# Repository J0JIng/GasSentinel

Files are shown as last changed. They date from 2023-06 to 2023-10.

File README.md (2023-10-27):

# GasSentinel

## Overview 
Gas leaks can be dangerous but hard to detect. This project aims to use edge AI to provide low-latency, accurate detection of gas leaks. In particular, these are propane, butane and natural gas.<br>
It is also possible to detect indicative gases such as H<sub>2</sub>S.

## Algorithm and Detection Principles
Interpreting gas sensor resistances is complex and may require specialized knowledge in electrochemical sensor behaviors. Resistance of the sensing element is nontrivially influenced by ambient conditions, and even past gas exposure events. As such, this situation provides an opportunity to utilize ML techniques to interpret the data.<br>

This project utilizes the BSEC software (which runs on the microcontroller) to run the associated signal processing/fusion and ML model. Refer to Figure 1 below for the confusion matrix and F1 scores:<br>

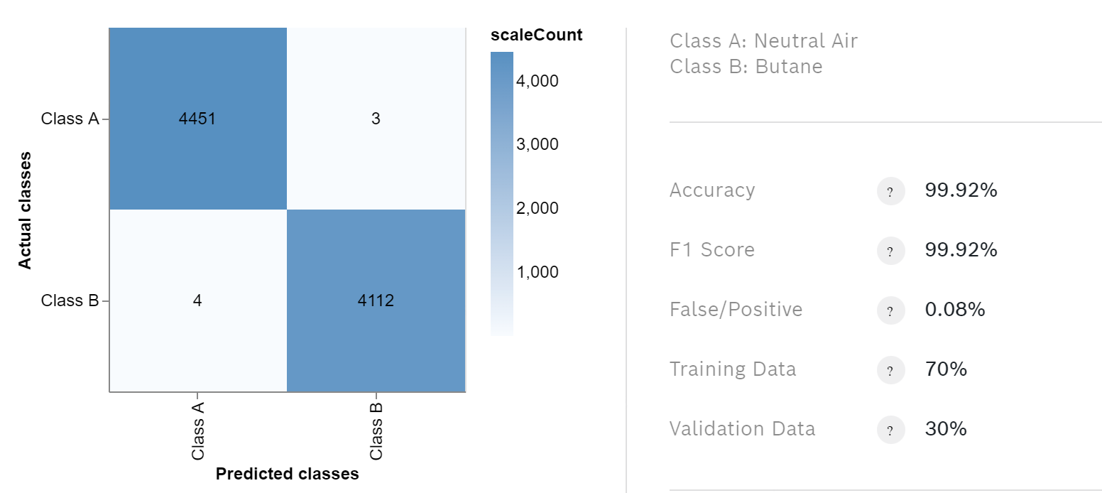
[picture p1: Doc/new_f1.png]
Confusion Matrix and F1
<br>

Figure 1: Confusion matrix and F1 scores (LP)<br>

The model was trained with low concentrations of butane, propane, etc.[^1] at room temperature/pressure at (or above) their respective Lower Explosive Limit (LEL). The model runs every 73.36s with a duty cycle of 25%.<br>
During training, the sensor was exposed to the following mixtures/gases:
| Mixture/Gas | Class |
|---|---|
| Outdoor Air | Baseline |
| Indoor Air (Normal)  | Baseline |
| Indoor Air (A/C) | Baseline |
| Indoor Air (Cooking) | Baseline |
| Perfumes | Baseline |
| Expired Air | Baseline |
| LPG Mix | Gas Leak |
| Butane | Gas Leak |

<br>

Additionally, for each $t \in [0, 18.34]s$ during a measurement cycle, the sensor heater is configured to have the profile[^2]:
```math
h(t) = \begin{cases}
   100°C, & \text{if } 0.28s \leq t \leq 6.02s, \\
  200°C, & \text{if } 6.3s \leq t \leq 12.18s, \\
  320°C, & \text{if } 12.46s \leq t \leq 18.34s.
\end{cases}
```
where the undefined intervals are transition (i.e. ramp-up/down) periods. This heater activity is responsible for the majority of the power consumption (>12mA), where other loads (i.e. microcontroller+RF) are negligible. Hence, the battery life is almost directly proportional to the measurement duty cycle. For this particular application, a duty cycle of 25% was found to yield a good balance between response time (73.36s) and power consumption (avg. 2.1mA).<br>
Note that if USB power is detected at startup, a 100% duty cycle high performance model will be loaded instead.
<br>

## System Design
For this particular application, it is vital that warning latencies are kept low. This project provides on-device inference, which allows for rapid reaction to events, and low data transmission overhead.<br>
Additionally, the device has a low-latency Thread network connection (compared to BLE/Zigbee) for offsite notifications and action triggering, which is also low-power, allowing for operation either from USB power, or from AA batteries. <br>

The power consumed by the stepwise heater function accounts for the majority of the system power consumption. The system quiescent current I<sub>Q</sub> by design is stated below:<br>
$I_{Q} = I_{EM2(MGM240P)} + I_{DDSB(BME688)} + I_{Q(TPS2116)} + I_{SD(MX95)} + I_{SW(ST1PS03)}$<br>
$I_{Q} = 2.9μA + 0.15μA + 1.35μA + 7nA + 1μA$<br>
$I_{Q} = 5.4μA$<br>
Which is reflected in measurements. <br>

<br>
<div>
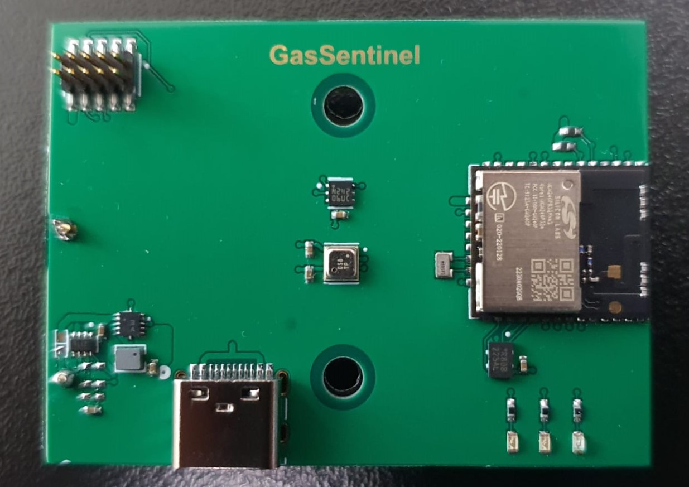
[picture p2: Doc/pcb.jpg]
PCB
    
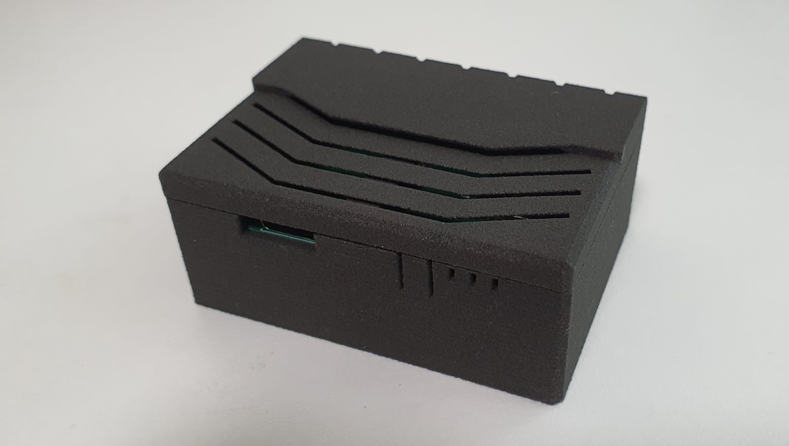
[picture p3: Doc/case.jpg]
Case
    
</div>

Figure 2: GasSentinel Custom Board and Enclosure<br>

The algorithms described above are run the onboard EFR32MG24 series microcontroller, with integrated 802.15.4 radio for Thread communications.<br>
The application layer overview for the microcontroller software can be found in Figure 3:<br><br>
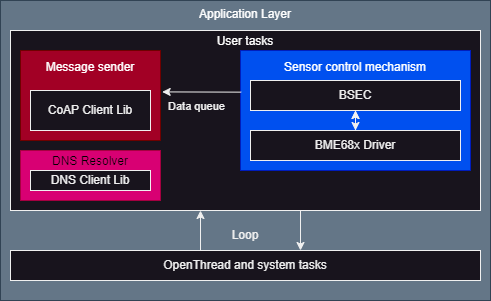
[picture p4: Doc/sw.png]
SW
<br>
Figure 3: Application-Layer Block Diagram (Microcontroller)<br>
<br>
The device will also send the inference results and other metadata over CoAP to InfluxDB for backend integration and data analytics/visualization.<br>

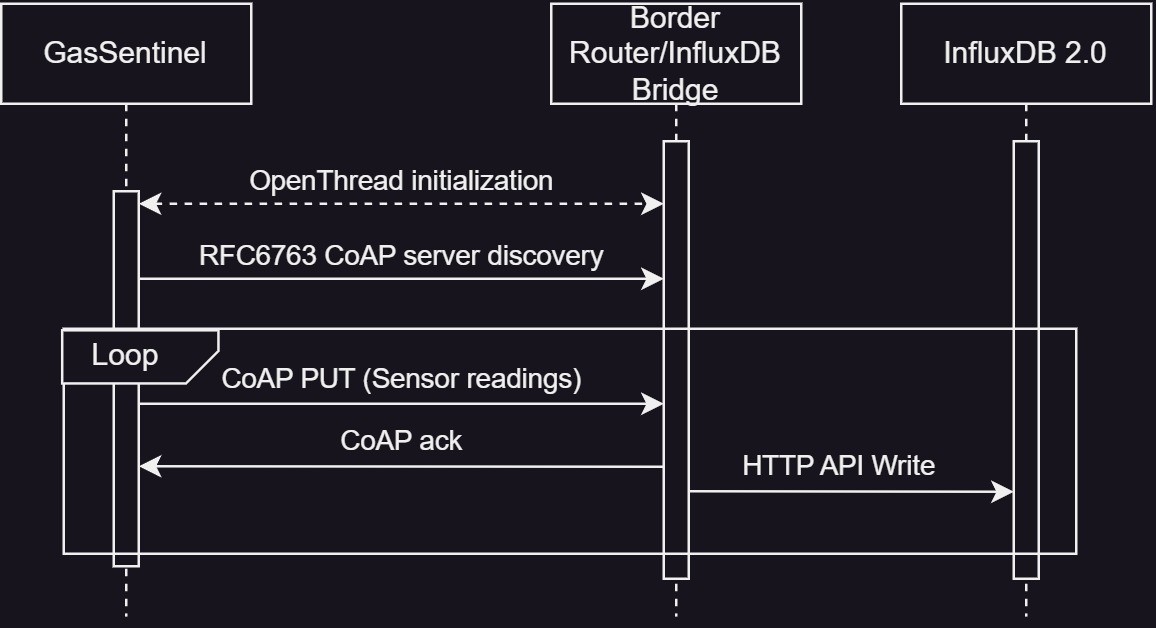
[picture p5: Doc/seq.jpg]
Seq
<br>
Figure 4: Messaging Sequence Diagram

## Performance Evaluation
The qualitative results of the low-power classifier are shown in Figure 5, over a period of approx. 2h, the device was subjected to 3 periods of the positive class (Gas Leak), denoted by the "Ground Truth" label.<br>
In general, the model has a recovery period of minimally a few cycles, after being exposed to the positive class. Some of this behavior can be attributed to the behaviors of the MOx element. In particular, the first instance of the positive class in Figure 5 shows that the recovery time is much greater after exposure to high concentrations of gas.<br>

It is notable that in all instances, (correct) detection occured within one cycle (i.e. 73.36s), satisfying the objective of rapid classification.<br>
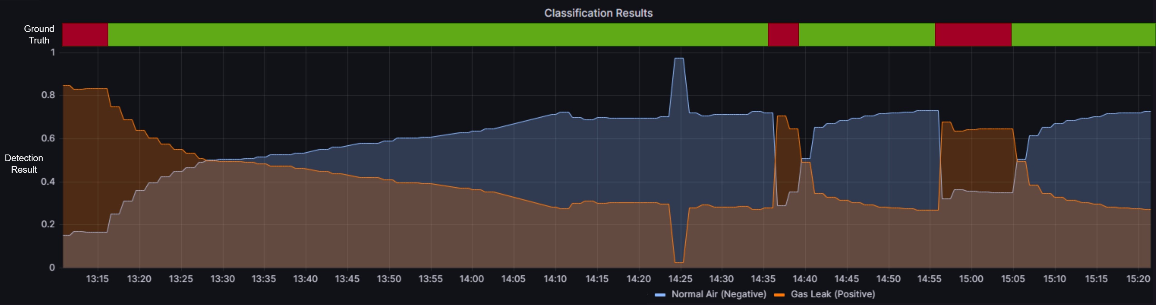
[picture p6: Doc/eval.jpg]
Eval
<br>
Figure 5: Qualitative results of the low-power classifier
## 
[^1]: Note that methane (despite being found in gas leaks) was categorically avoided, as methane cannot be detected significantly by the sensor.
[^2]: This profile was found to yield the highest F1 score and generalization to test/live data.

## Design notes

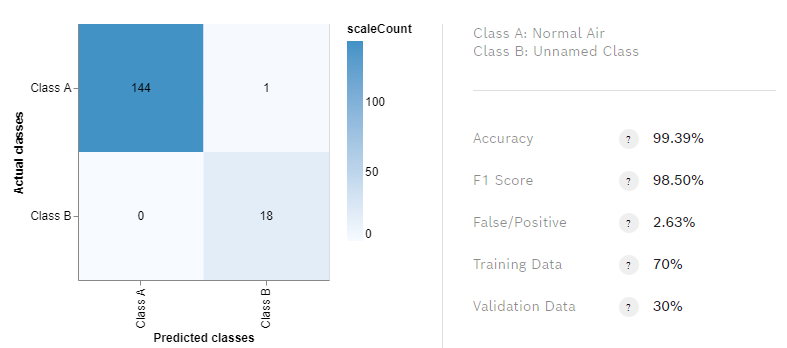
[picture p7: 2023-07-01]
Doc/f1_lp.png

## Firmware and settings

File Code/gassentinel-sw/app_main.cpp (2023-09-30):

#include "app_dns.h"
#include "app_thread.h"
#include "app_sensor.h"
#include "app_coap.h"
#include <app_main.h>
#include <assert.h>
#include <config/bsec_selectivity.h>
#include <openthread-core-config.h>
#include <openthread/config.h>

#include <openthread/cli.h>
#include <openthread/diag.h>
#include <openthread/tasklet.h>
#include <openthread/thread.h>

#include "openthread-system.h"
#include "em_system.h"
#include "sl_component_catalog.h"
#include "em_burtc.h"
#include "em_prs.h"
#include "em_iadc.h"
#include "bme68x.h"
#include "bsec_interface.h"
#include "sl_i2cspm.h"
#include "sl_sleeptimer.h"
#include "sl_udelay.h"
#include "mx25_driver.h"

#include <cstring>
#include <cmath>

// Forward declarations
void sleepyInit(void);
void setNetworkConfiguration(void);
void initUdp(void);
void app_init_bme(uint8_t sense_pin);

// DNS related variables
dns DNS(otGetInstance, 4, 4);
static otIp6Address server;
static bool found_server = false;
static bool pend_resolve_server = false;
constexpr static char *endpoint_dnssd_name = "_coap._udp.default.service.arpa.";

// BME/BSEC related variables
struct bme68x_dev bme;
static uint8_t bme_addr = BME68X_I2C_ADDR_LOW;
static volatile bool bsec_run = true;
uint8_t work_buffer[BSEC_MAX_WORKBUFFER_SIZE];
uint8_t bsec_state[BSEC_MAX_STATE_BLOB_SIZE];

sl_sleeptimer_timer_handle_t resolve_server_timer;
constexpr static uint32_t RESOLVE_POST_EST_CONN_MS = 5000;

const static uint32_t FLASH_PAGE_SIZE_U = 0x100;
static uint32_t FLASH_DATA_VALID_REGION_START = 0x000F1000; // BLOCK 15 SECTOR 241
static uint32_t FLASH_DATA_VALID_REGION_LEN = 0x4;
static uint8_t FLASH_DATA_VALID_MARKER[4] = { 0x2F, 0xC6, 0x9A, 0x44 };

static uint32_t FLASH_DATA_WBUF_REGION_START = 0x00001000; // BLOCK 0 SECTOR 1

static uint32_t FLASH_DATA_WBUF_REGION_LEN = BSEC_MAX_WORKBUFFER_SIZE;

static uint32_t FLASH_DATA_BLOB_REGION_START = 0x00011000; // BLOCK 1 SECTOR 17

static uint32_t FLASH_DATA_BLOB_REGION_LEN = BSEC_MAX_STATE_BLOB_SIZE;

const static uint32_t FLASH_PGM_RETRY_MAX = 50;

sl_sleeptimer_timer_handle_t flash_save_timer;
constexpr static uint32_t FLASH_SAVE_INTERVAL_MS = 1 * 60 * 60 * 1000;  // 1 hour
static bool pend_save_flash = false;

uint8_t _app_mx25_write_data(void);
uint8_t _app_mx25_get_data(void);
uint8_t _app_mx25_get_state(void);


eui_t eui; // Device unique identifier


static enum { // Denotes power mode
	BATT = 0,
	USB = 1,
} power_source;

extern "C" void otAppCliInit(otInstance *aInstance);

static otInstance* sInstance = NULL;

static BME68X_INTF_RET_TYPE app_i2c_plat_read(uint8_t reg_addr, uint8_t *reg_data,
		uint32_t length, void *intf_ptr);
static BME68X_INTF_RET_TYPE app_i2c_plat_write(uint8_t reg_addr, const uint8_t *reg_data,
		uint32_t length, void *intf_ptr);


void app_init_bme(void);
void app_burtc_callback(uint32_t dur);

/* Interrupt handler for BURTC */
void BURTC_IRQHandler(void)
{
    BURTC_IntClear(BURTC_IF_COMP); // compare match
	BURTC_CounterReset();
	BURTC_Stop();
	bsec_run = true;
	BURTC_IntDisable(BURTC_IEN_COMP);
}

/* Callback function for resetting BURTC in sensor proc context */
void app_burtc_callback(uint32_t dur)
{
	BURTC_CounterReset();
	BURTC_CompareSet(0, dur);
	BURTC_IntEnable(BURTC_IEN_COMP);
}

/* Interrupt handler for IADC */
void IADC_IRQHandler(void){
  IADC_Result_t sample;
  sample = IADC_pullSingleFifoResult(IADC0);
  coap::vsense_batt = (sample.data * 1200)/1000;
  IADC_clearInt(IADC0, IADC_IF_SINGLEDONE);
}

/* Callback function for DNS resolve */
void resolveServerHandler(sl_sleeptimer_timer_handle_t *handle, void *data)
{
	pend_resolve_server = true;
}

void flashSaveHandler(sl_sleeptimer_timer_handle_t *handle, void *data)
{
	pend_save_flash = true;
}

/* Getter function for otinstance */
otInstance *otGetInstance(void)
{
    return sInstance;
}

/** Application initialization **/
void app_init(void) {

	GPIO_PinOutSet(ERR_LED_PORT, ERR_LED_PIN);
	uint8_t sense = 0x1 & GPIO_PinInGet(SW_PWR_SRC_PORT, SW_PWR_SRC_PIN); // Read input power source and mask first bit
	app_init_bme(sense);
	GPIO_PinModeSet(SW_PWR_SRC_PORT, SW_PWR_SRC_PIN, gpioModeDisabled, 0); // Disable after read to reduce static power
	/* ot initialization procedure */
	sleepyInit();
	setNetworkConfiguration();

	assert(otIp6SetEnabled(sInstance, true) == OT_ERROR_NONE);
	assert(otThreadSetEnabled(sInstance, true) == OT_ERROR_NONE);

	/* dns initialization procedure */
	appSrpInit();
	sl_sleeptimer_start_timer_ms(&resolve_server_timer, RESOLVE_POST_EST_CONN_MS, resolveServerHandler, NULL, 0, 0);
	sl_sleeptimer_start_periodic_timer_ms(&flash_save_timer, FLASH_SAVE_INTERVAL_MS, flashSaveHandler, NULL, 0, 0);

	found_server = false;
	pend_resolve_server = false;

	//otCliOutputFormat("[APP MAIN][I] Initialization successful \n");
	eui._64b = SYSTEM_GetUnique();
	coap::init();
	GPIO_PinOutSet(IP_LED_PORT, IP_LED_PIN);
	GPIO_PinOutClear(ERR_LED_PORT, ERR_LED_PIN);
}


/** Application main loop **/

void app_process_action(void)
{
	/** System tasks **/
	otTaskletsProcess(sInstance);
	otSysProcessDrivers(sInstance);

	/** DNS resolution yield **/
	/*
	if(pend_resolve_server) {
		pend_resolve_server = false;
		DNS.browse(endpoint_dnssd_name);
		//otCliOutputFormat("[APP MAIN][I] search started\n");
		GPIO_PinOutSet(IP_LED_PORT, IP_LED_PIN);
	}
	if(!found_server)
	{
		otDnsServiceInfo *info;
		uint8_t sz = 0;
		if(DNS.browseResultReady(&info, &sz))
		{
			if(sz == 0) {
				//otCliOutputFormat("[APP MAIN][W] Failed search \n");
				pend_resolve_server = true;
				GPIO_PinOutSet(ERR_LED_PORT, ERR_LED_PIN);
			}
			else {
				//otCliOutputFormat("[APP MAIN][I] Server found \n");
				server = (*info).mHostAddress;
				char string[OT_IP6_ADDRESS_STRING_SIZE];
				otIp6AddressToString(&server, string, sizeof(string));
				//otCliOutputFormat("[APP MAIN][I] Server IPv6 resolved as %s\n", string);
				found_server = true;
				coap::init(server);
				GPIO_PinOutClear(ERR_LED_PORT, ERR_LED_PIN);
			}
			GPIO_PinOutClear(IP_LED_PORT, IP_LED_PIN);
		} else GPIO_PinOutToggle(IP_LED_PORT, IP_LED_PIN);

	}
	*/
	GPIO_PinOutSet(ACT_LED_PORT, ACT_LED_PIN);

	/** sensor algo yield **/
	if (bsec_run) {
		bsec_run = false;
		sensor::proc(app_burtc_callback);
	}

	/** coap yield **/
	coap::service();


	if(pend_save_flash) {_app_mx25_write_data(); pend_save_flash = false; }


	GPIO_PinOutClear(ACT_LED_PORT, ACT_LED_PIN);

}



void app_delay_us(uint32_t period, void *intf_ptr)
{
	sl_sleeptimer_delay_millisecond(period/1000);
}


uint8_t _app_mx25_get_state(void)
{
	uint8_t ret = 0;
	uint8_t buf[4];
	ret = MX25_READ(FLASH_DATA_VALID_REGION_START, buf, FLASH_DATA_VALID_REGION_LEN);
	for(uint8_t i=0; i<sizeof(buf); i++)
	{
		if(buf[i] != FLASH_DATA_VALID_MARKER[i]) return 0;
	}
	return 1;
}

uint8_t _app_mx25_get_data(void)
{
	GPIO_PinOutSet(ACT_LED_PORT, ACT_LED_PIN);
	uint8_t ret = 0;
	ret = MX25_READ(FLASH_DATA_WBUF_REGION_START, work_buffer, FLASH_DATA_WBUF_REGION_LEN);
	if(ret != 0) return 0;
	ret = MX25_READ(FLASH_DATA_BLOB_REGION_START, bsec_state, FLASH_DATA_BLOB_REGION_LEN);
	GPIO_PinOutClear(ACT_LED_PORT, ACT_LED_PIN);
	if(ret != 0) return 0;
	else return 1;
}

uint8_t _app_mx25_write_data(void) {
	GPIO_PinOutSet(ACT_LED_PORT, ACT_LED_PIN);
	uint8_t ret = 0;
	uint32_t array_idx = 0, seg, timeout = 0;
	while (array_idx < FLASH_DATA_BLOB_REGION_LEN) {
		seg = (FLASH_DATA_BLOB_REGION_LEN - array_idx) >= FLASH_PAGE_SIZE_U ?
				FLASH_PAGE_SIZE_U : (FLASH_DATA_BLOB_REGION_LEN - array_idx);

		ret = MX25_PP(FLASH_DATA_BLOB_REGION_START + array_idx,
				&bsec_state[array_idx], seg);
		if (ret == FlashOperationSuccess) {

			GPIO_PinOutToggle(ACT_LED_PORT, ACT_LED_PIN);
			array_idx += seg;
			timeout = 0;
		} else {
			if(timeout > FLASH_PGM_RETRY_MAX) return 0;
			timeout++;
		}
	}
	array_idx = 0;
	seg = 0;
	timeout = 0;
	while (array_idx < FLASH_DATA_WBUF_REGION_LEN) {
		seg = (FLASH_DATA_WBUF_REGION_LEN - array_idx) >= FLASH_PAGE_SIZE_U ?
				FLASH_PAGE_SIZE_U : (FLASH_DATA_WBUF_REGION_LEN - array_idx);

		ret = MX25_PP(FLASH_DATA_WBUF_REGION_START + array_idx,
				&bsec_state[array_idx], seg);
		if (ret == FlashOperationSuccess) {

			GPIO_PinOutToggle(ACT_LED_PORT, ACT_LED_PIN);
			array_idx += seg;
			timeout = 0;
		} else {
			if(timeout > FLASH_PGM_RETRY_MAX) return 0;
			timeout++;
		}
	}
	ret = MX25_PP(FLASH_DATA_VALID_REGION_START, FLASH_DATA_VALID_MARKER, FLASH_DATA_VALID_REGION_LEN);
	GPIO_PinOutClear(ACT_LED_PORT, ACT_LED_PIN);
	MX25_DP();
	sl_udelay_wait(30); // tDPDD
	return !(ret&0x1);
}

void app_init_bme(uint8_t sense_pin)
{
	memset(&bme, 0, sizeof(bme));
	bme.intf = BME68X_I2C_INTF;
	bme.read = app_i2c_plat_read;
	bme.write = app_i2c_plat_write;
	bme.delay_us = app_delay_us;
	bme.intf_ptr = &bme_addr;
	bme.amb_temp = 31; // TODO ref. sht22 bl calib
	assert(bme68x_init(&bme) == BME68X_OK);
	volatile int8_t ret = 0;

	 //otCliOutputFormat("[APP MAIN][I] BSEC ret codes: %d / ", ret);

	ret = bsec_init();
	//otCliOutputFormat("%d / ", ret);

	/* Set configuration according to detected power source */
	uint8_t is_exist_wbuf = _app_mx25_get_state();
	// TODO: modify work buffer to save to spi flash
	if (sense_pin == BATT) {
		uint32_t bsec_config_len = sizeof(bsec_config_selectivity);
		ret = bsec_set_configuration(bsec_config_selectivity, bsec_config_len,
				work_buffer, sizeof(work_buffer));
	}

	else if (sense_pin == USB) {
		uint32_t bsec_config_len = sizeof(bsec_config_selectivity_std);
		ret = bsec_set_configuration(bsec_config_selectivity_std, bsec_config_len,
				work_buffer, sizeof(work_buffer));
		GPIO_PinOutSet(ERR_LED_PORT, ERR_LED_PIN);
		GPIO_PinOutSet(ACT_LED_PORT, ACT_LED_PIN);
		GPIO_PinOutSet(IP_LED_PORT, IP_LED_PIN);
		sl_sleeptimer_delay_millisecond(1500);
		GPIO_PinOutClear(ERR_LED_PORT, ERR_LED_PIN);
		GPIO_PinOutClear(ACT_LED_PORT, ACT_LED_PIN);
		GPIO_PinOutClear(IP_LED_PORT, IP_LED_PIN);
	}
	if(!_app_mx25_write_data()) GPIO_PinOutSet(ERR_LED_PORT, ERR_LED_PIN);
	if(is_exist_wbuf) _app_mx25_get_data();

	MX25_DP();

	bsec_set_state(bsec_state, sizeof(bsec_state), work_buffer, sizeof(work_buffer));

	GPIO_PinOutSet(ACT_LED_PORT, ACT_LED_PIN);

	//otCliOutputFormat("%d / ", ret);
	GPIO_PinOutClear(ACT_LED_PORT, ACT_LED_PIN);

	bsec_sensor_configuration_t requested_virtual_sensors[9];
	uint8_t n_requested_virtual_sensors = 9;

	bsec_sensor_configuration_t required_sensor_settings[BSEC_MAX_PHYSICAL_SENSOR];
	uint8_t n_required_sensor_settings = BSEC_MAX_PHYSICAL_SENSOR;

	// virtual sensor configuration
    requested_virtual_sensors[0].sensor_id = BSEC_OUTPUT_GAS_ESTIMATE_1;
    requested_virtual_sensors[0].sample_rate = BSEC_SAMPLE_RATE_SCAN;
    requested_virtual_sensors[1].sensor_id = BSEC_OUTPUT_GAS_ESTIMATE_2;
    requested_virtual_sensors[1].sample_rate = BSEC_SAMPLE_RATE_SCAN;
    requested_virtual_sensors[2].sensor_id = BSEC_OUTPUT_GAS_ESTIMATE_3;
    requested_virtual_sensors[2].sample_rate = BSEC_SAMPLE_RATE_SCAN;
    requested_virtual_sensors[3].sensor_id = BSEC_OUTPUT_GAS_ESTIMATE_4;
    requested_virtual_sensors[3].sample_rate = BSEC_SAMPLE_RATE_SCAN;
    requested_virtual_sensors[4].sensor_id = BSEC_OUTPUT_RAW_PRESSURE;
    requested_virtual_sensors[4].sample_rate = BSEC_SAMPLE_RATE_SCAN;
    requested_virtual_sensors[5].sensor_id = BSEC_OUTPUT_RAW_TEMPERATURE;
    requested_virtual_sensors[5].sample_rate = BSEC_SAMPLE_RATE_SCAN;
    requested_virtual_sensors[6].sensor_id = BSEC_OUTPUT_RAW_HUMIDITY;
    requested_virtual_sensors[6].sample_rate = BSEC_SAMPLE_RATE_SCAN;
    requested_virtual_sensors[7].sensor_id = BSEC_OUTPUT_RAW_GAS;
    requested_virtual_sensors[7].sample_rate = BSEC_SAMPLE_RATE_SCAN;
    requested_virtual_sensors[8].sensor_id = BSEC_OUTPUT_RAW_GAS_INDEX;
    requested_virtual_sensors[8].sample_rate = BSEC_SAMPLE_RATE_SCAN;


	ret = bsec_update_subscription(requested_virtual_sensors,
					n_requested_virtual_sensors, required_sensor_settings,
					&n_required_sensor_settings);
	 //otCliOutputFormat("%d\n", ret);
	 bsec_version_t ver;
	 bsec_get_version(&ver);
	 //otCliOutputFormat("[APP MAIN][I] BSEC Version: v%d.%d.%d.%d\n", ver.major,ver.minor,ver.major_bugfix,ver.minor_bugfix);
}






void app_exit(void)
{
    otInstanceFinalize(sInstance);
}


void sl_ot_create_instance(void)
{

    sInstance = otInstanceInitSingle();
    assert(sInstance);
}

void sl_ot_cli_init(void)
{
    //otAppCliInit(sInstance);
}

static BME68X_INTF_RET_TYPE app_i2c_plat_read(uint8_t reg_addr, uint8_t *reg_data,
		uint32_t length, void *intf_ptr) {

	I2C_TransferSeq_TypeDef i2cTransfer;
	uint8_t device_addr = *(uint8_t*)intf_ptr;
	// Initialize I2C transfer
	i2cTransfer.addr = device_addr << 1;
	i2cTransfer.flags = I2C_FLAG_WRITE_READ; // must write target address before reading
	i2cTransfer.buf[0].data = &reg_addr;
	i2cTransfer.buf[0].len = 1;
	i2cTransfer.buf[1].data = reg_data;
	i2cTransfer.buf[1].len = (uint16_t)length;

	return I2CSPM_Transfer(I2C0, &i2cTransfer);

}

static BME68X_INTF_RET_TYPE app_i2c_plat_write(uint8_t reg_addr, const uint8_t *reg_data,
		uint32_t length, void *intf_ptr) {

	I2C_TransferSeq_TypeDef i2cTransfer;
	uint8_t device_addr = *(uint8_t*)intf_ptr;
	// Initialize I2C transfer
	i2cTransfer.addr = device_addr << 1;
	i2cTransfer.flags = I2C_FLAG_WRITE_WRITE;
	i2cTransfer.buf[0].data = &reg_addr;
	i2cTransfer.buf[0].len = 1;
	i2cTransfer.buf[1].data = (uint8_t *)reg_data;
	i2cTransfer.buf[1].len = (uint16_t)length;

	return I2CSPM_Transfer(I2C0, &i2cTransfer);
}

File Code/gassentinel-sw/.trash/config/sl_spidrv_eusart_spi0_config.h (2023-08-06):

/***************************************************************************//**
 * @file
 * @brief SPIDRV_EUSART Config
 *******************************************************************************
 * # License
 * <b>Copyright 2019 Silicon Laboratories Inc. www.silabs.com</b>
 *******************************************************************************
 *
 * SPDX-License-Identifier: Zlib
 *
 * The licensor of this software is Silicon Laboratories Inc.
 *
 * This software is provided 'as-is', without any express or implied
 * warranty. In no event will the authors be held liable for any damages
 * arising from the use of this software.
 *
 * Permission is granted to anyone to use this software for any purpose,
 * including commercial applications, and to alter it and redistribute it
 * freely, subject to the following restrictions:
 *
 * 1. The origin of this software must not be misrepresented; you must not
 *    claim that you wrote the original software. If you use this software
 *    in a product, an acknowledgment in the product documentation would be
 *    appreciated but is not required.
 * 2. Altered source versions must be plainly marked as such, and must not be
 *    misrepresented as being the original software.
 * 3. This notice may not be removed or altered from any source distribution.
 *
 ******************************************************************************/

#ifndef SL_SPIDRV_EUSART_SPI0_CONFIG_H
#define SL_SPIDRV_EUSART_SPI0_CONFIG_H

#include "spidrv.h"

// <<< Use Configuration Wizard in Context Menu >>>
// <h> SPIDRV settings

// <o SL_SPIDRV_EUSART_SPI0_BITRATE> SPI bitrate
// <i> Default: 1000000
#define SL_SPIDRV_EUSART_SPI0_BITRATE           1000000

// <o SL_SPIDRV_EUSART_SPI0_FRAME_LENGTH> SPI frame length <7-16>
// <i> Default: 8
#define SL_SPIDRV_EUSART_SPI0_FRAME_LENGTH      8

// <o SL_SPIDRV_EUSART_SPI0_TYPE> SPI mode
// <spidrvMaster=> Master
// <spidrvSlave=> Slave
#define SL_SPIDRV_EUSART_SPI0_TYPE              spidrvMaster

// <o SL_SPIDRV_EUSART_SPI0_BIT_ORDER> Bit order on the SPI bus
// <spidrvBitOrderLsbFirst=> LSB transmitted first
// <spidrvBitOrderMsbFirst=> MSB transmitted first
#define SL_SPIDRV_EUSART_SPI0_BIT_ORDER         spidrvBitOrderMsbFirst

// <o SL_SPIDRV_EUSART_SPI0_CLOCK_MODE> SPI clock mode
// <spidrvClockMode0=> SPI mode 0: CLKPOL=0, CLKPHA=0
// <spidrvClockMode1=> SPI mode 1: CLKPOL=0, CLKPHA=1
// <spidrvClockMode2=> SPI mode 2: CLKPOL=1, CLKPHA=0
// <spidrvClockMode3=> SPI mode 3: CLKPOL=1, CLKPHA=1
#define SL_SPIDRV_EUSART_SPI0_CLOCK_MODE        spidrvClockMode0

// <o SL_SPIDRV_EUSART_SPI0_CS_CONTROL> SPI master chip select (CS) control scheme.
// <spidrvCsControlAuto=> CS controlled by the SPI driver
// <spidrvCsControlApplication=> CS controlled by the application
#define SL_SPIDRV_EUSART_SPI0_CS_CONTROL        spidrvCsControlAuto

// <o SL_SPIDRV_EUSART_SPI0_SLAVE_START_MODE> SPI slave transfer start scheme
// <spidrvSlaveStartImmediate=> Transfer starts immediately
// <spidrvSlaveStartDelayed=> Transfer starts when the bus is idle (CS deasserted)
// <i> Only applies if instance type is spidrvSlave
#define SL_SPIDRV_EUSART_SPI0_SLAVE_START_MODE  spidrvSlaveStartImmediate
// </h>
// <<< end of configuration section >>>

// <<< sl:start pin_tool >>>
// <eusart signal=TX,RX,SCLK,(CS)> SL_SPIDRV_EUSART_SPI0
// $[EUSART_SL_SPIDRV_EUSART_SPI0]
#ifndef SL_SPIDRV_EUSART_SPI0_PERIPHERAL        
#define SL_SPIDRV_EUSART_SPI0_PERIPHERAL         EUSART1
#endif
#ifndef SL_SPIDRV_EUSART_SPI0_PERIPHERAL_NO     
#define SL_SPIDRV_EUSART_SPI0_PERIPHERAL_NO      1
#endif

// EUSART1 TX on PC02
#ifndef SL_SPIDRV_EUSART_SPI0_TX_PORT           
#define SL_SPIDRV_EUSART_SPI0_TX_PORT            gpioPortC
#endif
#ifndef SL_SPIDRV_EUSART_SPI0_TX_PIN            
#define SL_SPIDRV_EUSART_SPI0_TX_PIN             2
#endif

// EUSART1 RX on PC01
#ifndef SL_SPIDRV_EUSART_SPI0_RX_PORT           
#define SL_SPIDRV_EUSART_SPI0_RX_PORT            gpioPortC
#endif
#ifndef SL_SPIDRV_EUSART_SPI0_RX_PIN            
#define SL_SPIDRV_EUSART_SPI0_RX_PIN             1
#endif

// EUSART1 SCLK on PC03
#ifndef SL_SPIDRV_EUSART_SPI0_SCLK_PORT         
#define SL_SPIDRV_EUSART_SPI0_SCLK_PORT          gpioPortC
#endif
#ifndef SL_SPIDRV_EUSART_SPI0_SCLK_PIN          
#define SL_SPIDRV_EUSART_SPI0_SCLK_PIN           3
#endif

// EUSART1 CS on PC04
#ifndef SL_SPIDRV_EUSART_SPI0_CS_PORT           
#define SL_SPIDRV_EUSART_SPI0_CS_PORT            gpioPortC
#endif
#ifndef SL_SPIDRV_EUSART_SPI0_CS_PIN            
#define SL_SPIDRV_EUSART_SPI0_CS_PIN             4
#endif
// [EUSART_SL_SPIDRV_EUSART_SPI0]$
// <<< sl:end pin_tool >>>

#endif // SL_SPIDRV_EUSART_SPI0_CONFIG_HEUSART_

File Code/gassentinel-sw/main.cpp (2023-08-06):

#include <app_main.h>
#include <mx25_driver.h>
#include "sl_component_catalog.h"
#include "sl_system_init.h"
#include "sl_power_manager.h"
#include "sl_system_process_action.h"
#include "em_burtc.h"
#include "em_cmu.h"
#include "em_prs.h"
#include "em_iadc.h"
#include "sl_udelay.h"

void initBURTC(void) {
	CMU_ClockSelectSet(cmuClock_EM4GRPACLK, cmuSelect_ULFRCO);
	CMU_ClockEnable(cmuClock_BURTC, true);
	CMU_ClockEnable(cmuClock_BURAM, true);

	BURTC_Init_TypeDef burtcInit = BURTC_INIT_DEFAULT;
	burtcInit.compare0Top = true; // reset counter when counter reaches compare value
	burtcInit.em4comp = true; // BURTC compare interrupt wakes from EM4 (causes reset)
	BURTC_Init(&burtcInit);
	BURTC_IntEnable(BURTC_IEN_COMP);      // compare match
	NVIC_EnableIRQ(BURTC_IRQn);
	BURTC_Enable(true);
}


void initGPIO(void) {
	CMU_ClockEnable(cmuClock_GPIO, true);

	GPIO_PinModeSet(IP_LED_PORT, IP_LED_PIN, gpioModePushPull, 0);
	GPIO_PinModeSet(ACT_LED_PORT, ACT_LED_PIN, gpioModePushPull, 0);
	GPIO_PinModeSet(ERR_LED_PORT, ERR_LED_PIN, gpioModePushPull, 0);
	GPIO_PinModeSet(SW_PWR_SRC_PORT, SW_PWR_SRC_PIN, gpioModeInputPullFilter, 1);
}

void initSupplyMonitor(void)
{
  IADC_Init_t init = IADC_INIT_DEFAULT;
  IADC_AllConfigs_t initAllConfigs = IADC_ALLCONFIGS_DEFAULT;
  IADC_InitSingle_t initSingle = IADC_INITSINGLE_DEFAULT;
  IADC_SingleInput_t singleInput = IADC_SINGLEINPUT_DEFAULT;

  CMU_ClockEnable (cmuClock_PRS, true);
  PRS_SourceAsyncSignalSet (0,
  PRS_ASYNC_CH_CTRL_SOURCESEL_MODEM,
                            PRS_MODEMH_PRESENT);
  PRS_ConnectConsumer (0, prsTypeAsync, prsConsumerIADC0_SINGLETRIGGER);
  CMU_ClockEnable (cmuClock_IADC0, true);
  initAllConfigs.configs[0].reference = iadcCfgReferenceInt1V2;
  initAllConfigs.configs[0].vRef = 1200;
  initAllConfigs.configs[0].osrHighSpeed = iadcCfgOsrHighSpeed2x;

  initAllConfigs.configs[0].adcClkPrescale = IADC_calcAdcClkPrescale (
      IADC0, 1000000, 0, iadcCfgModeNormal, init.srcClkPrescale);
  initSingle.triggerSelect = iadcTriggerSelPrs0PosEdge;
  initSingle.dataValidLevel = iadcFifoCfgDvl4;
  initSingle.start = true;
  singleInput.posInput = iadcPosInputPortBPin4;
  singleInput.negInput = iadcNegInputGnd;
  IADC_init (IADC0, &init, &initAllConfigs);
  IADC_initSingle (IADC0, &initSingle, &singleInput);
  IADC_clearInt (IADC0, _IADC_IF_MASK);
  IADC_enableInt (IADC0, IADC_IEN_SINGLEDONE);
  NVIC_ClearPendingIRQ (IADC_IRQn);
  NVIC_SetPriority(GPIO_ODD_IRQn, 7);
  NVIC_EnableIRQ (IADC_IRQn);
}



int main(void)
{

  sl_system_init();


  // LL check flash HW
  MX25_init(); // wait tPUW
  uint8_t dat = 0x00;
  uint32_t id = 0;

  initBURTC();
  initGPIO();



  app_init();



  while (1) {

    sl_system_process_action(); // System tasks

    app_process_action(); // App tasks

    sl_power_manager_sleep(); // Hand over to power manager

  }
  // SHOULD NEVER EXECUTE
  app_exit();

}

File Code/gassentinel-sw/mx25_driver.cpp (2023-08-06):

/*
 * COPYRIGHT (c) 2010-2015 MACRONIX INTERNATIONAL CO., LTD
 * SPI Flash Low Level Driver (LLD) Sample Code
 *
 * SPI interface command set
 *
 * $Id: MX25_CMD.c,v 1.31 2015/03/24 01:06:33 mxclldb1 Exp $
 *
 * MODIFIED 1/8/23 for platform defined EUSART
 */

#include <mx25_driver.h>
#include "em_gpio.h"
#include "spidrv.h"
#include "em_cmu.h"
#include "em_usart.h"
#include "sl_spidrv_eusart_mx25_config.h"
#include "sl_spidrv_instances.h"

/* Local functions */

/* Basic functions */
void CS_High( void );
void CS_Low( void );
void InsertDummyCycle( uint8_t dummy_cycle );
void SendByte( uint8_t byte_value, uint8_t transfer_type );
uint8_t GetByte( uint8_t transfer_type );

/* Utility functions */
void Wait_Flash_WarmUp( void );
void Initial_Spi( void );
bool WaitFlashReady( uint32_t ExpectTime );
bool WaitRYBYReady( uint32_t ExpectTime );
bool IsFlashBusy( void );
bool IsFlashQIO( void );
bool IsFlash4Byte( void );
void SendFlashAddr( uint32_t flash_address, uint8_t io_mode, bool addr_4byte_mode );
uint8_t GetDummyCycle( uint32_t default_cycle );

void MX25_init( void )
{
	GPIO_PinModeSet(SL_SPIDRV_EUSART_MX25_CS_PORT, SL_SPIDRV_EUSART_MX25_CS_PIN, gpioModeInputPullFilter, 1);
   /* Wait for flash warm-up */
   Initial_Spi();
}


/*
 --Common functions
 */

/*
 * Function:       Wait_Flash_WarmUp
 * Arguments:      None.
 * Description:    Wait some time until flash read / write enable.
 * Return Message: None.
 */
void Wait_Flash_WarmUp()
{
    volatile int time_cnt = FlashFullAccessTime;
    while( time_cnt > 0 )
    {
        time_cnt--;
    }
}

/*
 * Function:       Initial_Spi
 * Arguments:      None
 * Description:    Initial spi flash state and wait flash warm-up
 *                 (enable read/write).
 * Return Message: None
 */
void Initial_Spi()
{
   // Wait flash warm-up
   Wait_Flash_WarmUp();
}

/*
 * Function:       CS_Low, CS_High
 * Arguments:      None.
 * Description:    Chip select go low / high.
 * Return Message: None.
 */
void CS_Low()
{
   GPIO_PinOutClear( SL_SPIDRV_EUSART_MX25_CS_PORT, SL_SPIDRV_EUSART_MX25_CS_PIN );
}

void CS_High()
{
   GPIO_PinOutSet( SL_SPIDRV_EUSART_MX25_CS_PORT, SL_SPIDRV_EUSART_MX25_CS_PIN );
}

/*
 * Function:       InsertDummyCycle
 * Arguments:      dummy_cycle, number of dummy clock cycle
 * Description:    Insert dummy cycle of SCLK
 * Return Message: None.
 */
void InsertDummyCycle( uint8_t dummy_cycle )
{
   int i;

   for( i = 0; i < dummy_cycle/8; i++ )
   {
	   uint8_t buf = 0xFF;
	   //USART_Tx(USART0, 0xFF);
	   SPIDRV_MTransmitB(sl_spidrv_eusart_mx25_handle, &buf, sizeof(buf));
   }
}

/*
 * Function:       SendByte
 * Arguments:      byte_value, data transfer to flash
 *                 transfer_type, select different type of I/O mode.
 *                 Seven mode:
 *                 SIO, single IO
 *                 DIO, dual IO
 *                 QIO, quad IO
 *                 PIO, parallel
 *                 DTSIO, double transfer rate SIO
 *                 DTDIO, double transfer rate DIO
 *                 DTQIO, double transfer rate QIO
 * Description:    Send one byte data to flash
 * Return Message: None.
 */
void SendByte( uint8_t byte_value, uint8_t transfer_type )
{
   switch( transfer_type )
   {
#ifdef SIO
   case SIO: // Single I/O
	   SPIDRV_MTransmitB(sl_spidrv_eusart_mx25_handle, &byte_value, 1);
		//USART_Tx(USART0, byte_value);
      break;
#endif
#ifdef DIO
   case DIO: // Dual I/O
      //--- IO mode not supported! ---//
      break;
#endif
#ifdef QIO
   case QIO: // Quad I/O
      //--- IO mode not supported! ---//
      break;
#endif
#ifdef PIO
    case PIO: // Parallel I/O
       //--- IO mode not supported! ---//
       break;
#endif
#ifdef DTSIO
   case DTSIO: // Double transfer rate Single I/O
      //--- IO mode not supported! ---//
      break;
#endif
#ifdef DTDIO
   case DTDIO: // Double transfer rate Dual I/O
      //--- IO mode not supported! ---//
      break;
#endif
#ifdef DTQIO
   case DTQIO: // Double transfer rate Quad I/O
      //--- IO mode not supported! ---//
      break;
#endif
   default:
      break;
   }
}


/*
 * Function:       GetByte
 * Arguments:      byte_value, data receive from flash
 *                 transfer_type, select different type of I/O mode.
 *                 Seven mode:
 *                 SIO, single IO
 *                 DIO, dual IO
 *                 QIO, quad IO
 *                 PIO, parallel IO
 *                 DTSIO, double transfer rate SIO
 *                 DTDIO, double transfer rate DIO
 *                 DTQIO, double transfer rate QIO
 * Description:    Get one byte data to flash
 * Return Message: 8 bit data
 */
uint8_t GetByte( uint8_t transfer_type )
{
   uint8_t data_buf;

   switch( transfer_type )
   {
#ifdef SIO
   case SIO: // Single I/O
      //--- insert your code here for single IO receive. ---//
	   SPIDRV_MReceiveB(sl_spidrv_eusart_mx25_handle, &data_buf, 1);
	   //data_buf = USART_Rx(USART0);
      break;
#endif
#ifdef DIO
   case DIO: // Dual I/O
      //--- IO mode not supported! ---//
      break;
#endif
#ifdef QIO
    case QIO: // Quad I/O
       //--- IO mode not supported! ---//
       break;
#endif
#ifdef PIO
   case PIO: // Parallel I/O
      //--- IO mode not supported! ---//
      break;
#endif
#ifdef DTSIO
   case DTSIO: // Double transfer rate Single I/O
      //--- IO mode not supported! ---//
      break;
#endif
#ifdef DTDIO
   case DTDIO: // Double transfer rate Dual I/O
      //--- IO mode not supported! ---//
      break;
#endif
#ifdef DTQIO
   case DTQIO: // Double transfer rate Qual I/O
      //--- IO mode not supported! ---//
#endif
   default:
      break;
   }

    return data_buf;
}

/*
 * Function:       WaitFlashReady
 * Arguments:      ExpectTime, expected time-out value of flash operations.
 *                 No use at non-synchronous IO mode.
 * Description:    Synchronous IO:
 *                 If flash is ready return TRUE.
 *                 If flash is time-out return FALSE.
 *                 Non-synchronous IO:
 *                 Always return TRUE
 * Return Message: TRUE, FALSE
 */
bool WaitFlashReady( uint32_t ExpectTime )
{
#ifndef NON_SYNCHRONOUS_IO
    volatile uint32_t temp = 0;
    while( IsFlashBusy() )
    {
        if( temp > ExpectTime )
        {
            return FALSE;
        }
        temp = temp + 1;
    }
    return TRUE;
#else
    return TRUE;
#endif
}
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

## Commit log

2023-05-23 Added PCB
    [OdorGuard.PrjPcb, PCB1.PcbDoc, mcu.SchDoc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]
2023-05-26 Board routing complete
    [OdorGuard.PrjPcb, PCB1.PcbDoc, mcu.SchDoc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]
2023-05-30 Added initial efr32 code
    [OdorGuard.PrjPcb, PCB1.PcbDoc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]
2023-06-10 Changed files to cpp and added dns framework
2023-06-19 Implemented BME68x
    Added platform BSEC wrapper
    Updated GSDK to 4.3.0
    Updated BME68x driver files
    Updated application logic
    Added BURTC handler and callback mechanism
    [PCB1.PcbDoc, bsec_iaq.csv, bsec_selectivity.csv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]
2023-06-21 Updated BSEC AI files
    [bsec.csv, bsec_iaq.csv, bsec_selectivity.csv]
2023-06-22 Updated readme and PCB rev2
    [PCB1.PcbDoc, mcu.SchDoc, supply.SchDoc]
2023-06-23 Improved application logic
    [supply.SchDoc]
2023-06-28 Cleaned repo
    [GasSentinel.PrjPcb, OdorGuard.PrjPcb, PCB1.PcbDoc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]
2023-06-30 PCB updated, general bugfixes and enhancements
    - Updated PCB to version 1.1
    - Renamed srp registration name
    - Modified coap payload structure to align with server
    - Added prs iadc battery voltage measurements
    - Minor bugfixes
    [GasSentinel.PrjPcb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]
2023-07-20 General stability improvements
    STABLE version
    - Removed debugging code
    - Removed EUSART logs
    - Removed runtime configuration options
    - Removed unused variables and functions
    - Fixed errata related to power source detection; added input internal PU w/ filter
    - Changed SED poll period from 2000->5000ms
    Note: Revert all TODO before deployment
    [app_coap.cpp, app_main.cpp, main.cpp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]
2023-08-05 Completed bsec spi flash implementation and general bugfixes
    [app_main.cpp, main.cpp, mx25_driver.cpp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]
2023-08-06 Fixed memory mapping errata
    [app_main.cpp]
